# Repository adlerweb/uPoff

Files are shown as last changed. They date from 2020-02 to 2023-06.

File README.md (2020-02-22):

# µPoff - External deep sleep circuit
*µPoff* is a circuit placed high-side between your power source and your microcontroller. It is designed to cut power to the µC until a external sensor activates it. Additionally a onboard RTC can wake the µC in programmed intervals.

It is mainly aimed at battery powered sensor applications like door sensors, which also should report their battery level and presence regularly.

## Pinout

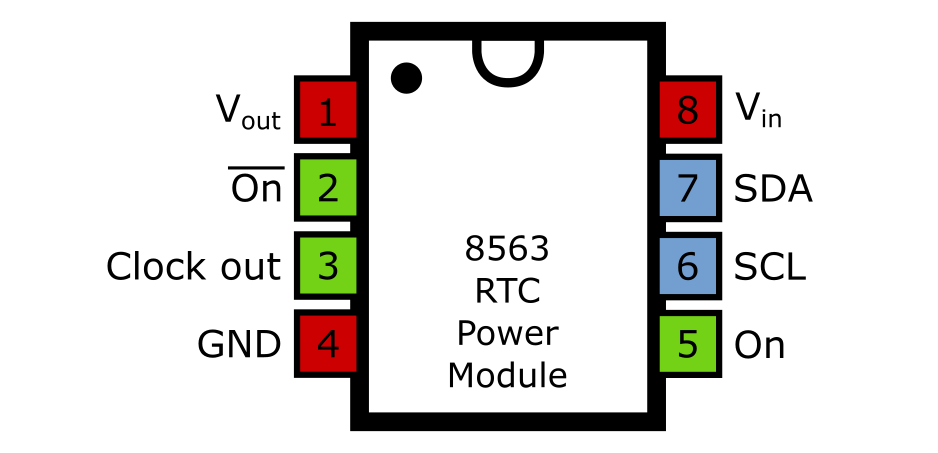
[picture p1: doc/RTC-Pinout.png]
Pinout diagram


## Connecting your µC

Remove the positive connection between your power source and µC. Connect the battery to **VCC** and your µC to **OUT**. Additionally connect **GND** to your existing ground. The external sensor should pull **^SW** low to activate the circuit. Lastly run a wire between one of your GPIO-Pins and **ON**. If you want to use the included RTC you'll also need to connect the I²C-Lines **SDA** and **SCL**. On AVR and STM32 based microcontrollers you'll have to use the predefined I²C pins, on ESP8266, ESP32 you can use any free GPIO.

## Software control

Usually power only stays on as long as **^ON** is low, however most tasks take longer to complete. To keep power on it is crucial to drive **ON** high as soon as your µC is started. When finished you can turn off power by driving **ON** LOW.

### Dependencies

 * Wire.h (usually included)
 * elpaso Rtc_Pcf8563 (https://github.com/elpaso/Rtc_Pcf8563)

### Manual wake only
```
#include "upoff.h"
UPOFF upoff;

void setup() {
  upoff.on(D1); //ON connected to D1
}

void loop() {
  //do something
  upoff.off();
}
```

### Manual and timed wake

```
#include "upoff.h"
UPOFF upoff;

bool reason;

void setup() {
  reason = upoff.on(D1, D2, D3); //D1 = ON; D2 = SDA; D3 = SCL
  //reason = upoff.on(D1, true); //Use predefined I²C-Pins

  /* Set clock */
  while(!upoff.isValid(false)) {
    upoff.setTime(20, 02, 02, 02, 02, 02); //2020-02-02 02:02:02
    yield();
  }
}

void loop() {
  pinMode(LED_BUILTIN, OUTPUT);
  if(reason) {
    /* either first boot or caused by RTC */
    byte loops=5;
    while(loops > 0) {
      digitalWrite(LED_BUILTIN, LOW);
      delay(100);
      digitalWrite(LED_BUILTIN, HIGH);
      delay(100);
      loops--;
    }
  }else{
    /* manual trigger */
    digitalWrite(LED_BUILTIN, LOW);
    delay(1000);
    digitalWrite(LED_BUILTIN, HIGH);
    delay(1000);
  }

  /* Sleep for 15 seconds */
  upoff.off(15);
}
```

## Power
While sleeping current draw for *µPoff* is ~10µA. Output should be fine for up to 1A.

## Common problems

### Boot-time vs. signal time
The external sensor has to keep **^ON** low until the µC is running and driving **ON**. Some µCs take several hundreds of milliseconds to boot. If your sensors pulse is too short you might be able to stretch it using some R+C magic.

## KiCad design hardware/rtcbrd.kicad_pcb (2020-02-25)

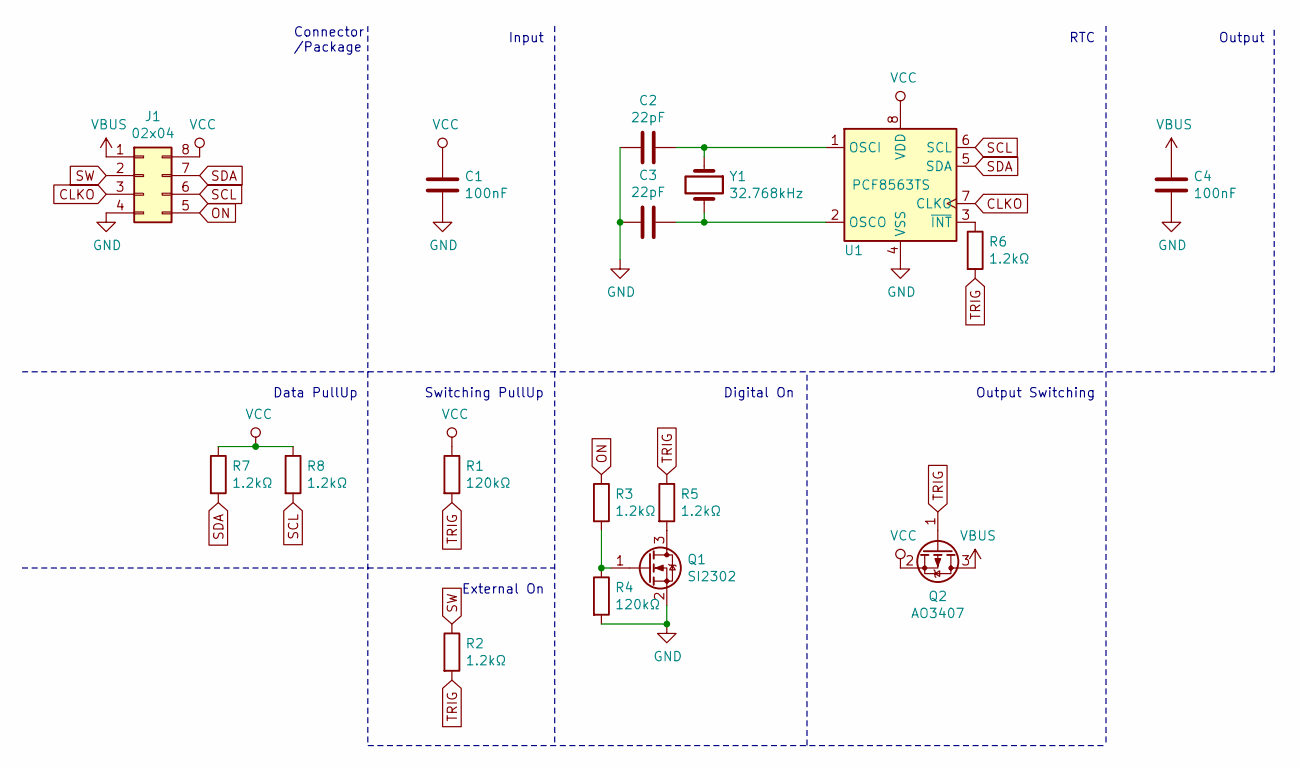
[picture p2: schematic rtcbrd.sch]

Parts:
C1, C4: 100nF; C_0402
C2, C3: 22pF; C_0402
J1: 02x04; DIP-8_W7.62mm
Q1: SI2302; SOT-23
Q2: AO3407; SOT-23
R1, R4: 120kΩ; R_0402
R2, R3, R5, R6, R7, R8: 1.2kΩ; R_0402
U1: PCF8563TS; HTSOP-8-1EP_3.9x4.9mm_Pitch1.27mm
Y1: 32.768kHz; Crystal_C38-LF_d3.0mm_l8.0mm_Horizontal

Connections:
CLKO: J1.3, U1.7 (CLKO)
GND: C1.1, C2.2, C3.2, C4.1, J1.4, Q1.2 (S), R4.2, U1.4 (VSS)
unnamed: C2.1, U1.1 (OSCI), Y1.1
unnamed: C3.1, U1.2 (OSCO), Y1.2
unnamed: Q1.1 (G), R3.2, R4.1
unnamed: Q1.3 (D), R5.2
unnamed: R6.1, U1.3 (~INT~)
ON: J1.5, R3.1
SCL: J1.6, R8.2, U1.6 (SCL)
SDA: J1.7, R7.2, U1.5 (SDA)
SW: J1.2, R2.1
TRIG: Q2.1 (G), R1.2, R2.2, R5.1, R6.2
VBUS: C4.2, J1.1, Q2.3 (D)
VCC: C1.2, J1.8, Q2.2 (S), R1.1, R7.1, R8.1, U1.8 (VDD)

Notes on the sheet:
Connector /Package
Input
RTC
Output
Output Switching
Digital On
Switching PullUp
External On
Data PullUp

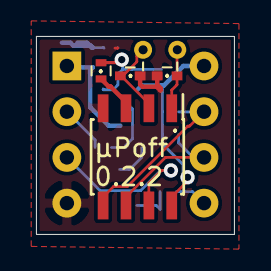
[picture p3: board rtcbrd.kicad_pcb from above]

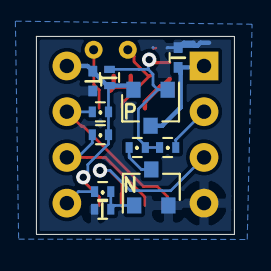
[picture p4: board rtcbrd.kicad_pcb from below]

Board: 2 copper layers, 11.0 x 11.0 mm, 17 parts (11 on the bottom side), 14 nets.

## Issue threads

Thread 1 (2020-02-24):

Missing i2c pullup resistors

FrederikWolter, 2020-02-24:

adlerweb, 2020-02-25:
https://github.com/adlerweb/uPoff/commit/7a002d55b8bd86f275d59c36e50ffc638167da36

Closed 2020-02-25.

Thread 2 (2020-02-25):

Component-List

JanLoebel, 2020-02-25:
Hi there,

I think for many people (specially beginner - like me) it would help to have a (example) component list and a wire-diagram without the pcb.

Example with Reichelt-Links (shop in Germany):

- U1: PCF8563TS -> https://www.reichelt.de/i-c-real-time-clock-tssop-8-pcf8563ts-5-p270122.html

- C2 / C3: 22pF Capacitor -> https://www.reichelt.de/glimmer-kondensator-22pf-100v-5-cy-22-2-22p-p42423.html

- C1 / C4: 100nF Capacitor -> https://www.reichelt.de/vielschicht-keramikkondensator-100n-10-x7r-2-5-100n-p22853.html

- R2 / R3 / R5 / R6: 1.2k Ohm Resistor -> https://www.reichelt.de/widerstand-metalloxyd-1-2-kohm-0207-1-0-w-5-1w-1-2k-p1768.html

- R1 / R4: 120k Ohm Resistor https://www.reichelt.de/widerstand-metalloxyd-120-kohm-0207-1-0-w-5-1w-120k-p1783.html

I'm missing the quartz crystal and the two mosfets, I was not able to find the right one so far. Of course you could also use other resistor/capacitor-types. Any other suggestions?

Best regards,
Jan

adlerweb, 2020-02-25:
When using KiCAD both are included. Also there is an interactive BOM located [inside the Hardware folder](https://raw.githubusercontent.com/adlerweb/uPoff/master/hardware/bom/ibom.html) - sadly GitHub doesn't render HTML directly, so you have to save and open it locally.

For your Links: I guess you're designing your own board or using a breadboard/prototype, otherwise you might want to check your footprints.

Crystal is [anything with 32.768kHz](https://www.reichelt.de/mini-uhrenquarz-0-032768-mhz-tc38-0-032768-p1089.html?), FETs are AO3407 (Q2/P) and SI2302 (Q1/N).

Items I used where mostly sourced from LCSC:

| Reference   | Quantity | Footprint | Value     | LCSC #  |
|-------------|----------|-----------|-----------|---------|
| C1,C4       | 2        | 0402      | 100nF     | C1525   |
| C2,C3       | 2        | 0402      | 22pF      | C115618 |
| R2,R3,R5,R6 | 4        | 0402      | 1.2kΩ     | C100581 |
| R1,R4       | 2        | 0402      | 120kΩ     | C384380 |
| U1          | 1        | HTSOP8    | PCF8563TS | C269877 |
| Y1          | 1        | C38       | 32.768kHz | C52082  |
| Q1          | 1        | SOT-23    | SI2302    | C351399 |
| Q2          | 1        | SOT-23    | AO3407    | C351408 |

JanLoebel, 2020-02-26:
Thanks :) I will have a look and KiCAD is new for me, so I will check how to see the wirediagramm. And yes I will start with a breadboard variant :) Thanks for the information!

Closed 2020-02-26.

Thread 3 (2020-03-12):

Missing ground connection at C2 & C3

FrederikWolter, 2020-03-12:
Hi,

I do not know if it is because I opened your board in EasyEDA, but I am shown that a ground connection of the two capacitors C2 & C3 is missing, since the ground plane is cut off by the quartz.

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

Isn't that necessary for the way it works?
Or should you make the connection in any case?

Thank you
Frederik

adlerweb, 2020-03-12:
Yes, GND is required. Seems to be a import bug in EasyEDA – ground is supposed to go between the RTC pins (and other places).
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
For me it looks like expansion is higher than intended (0.153mm or ~6mil). While you probably could add a trace there I would suggest to check expansion for both sides first, if you can fix it there there's probably a lower chance of errors in other parts of the board too.

FrederikWolter, 2020-03-12:
> looks like expansion is higher than intended (0.153mm or ~6mil)

It Works.
I almost thought that.
But I did not knew that EasyEDA overwrites these values when importing, nor to which value I should set it.

Thank you very much
Frederik

Closed 2020-03-12.

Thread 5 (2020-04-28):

RTC keeps VCCbus sometimes permanent high

FrederikWolter, 2020-04-28:
Hi,
I built the module (thanks for the idea). Everything works fine, except one thing.
Sometimes the RTC-Module gets stuck in the "ON-Position".
I use an Wemos D1 mini with the following code:

#include <Arduino.h>
#include "upoff.h"
UPOFF upoff;
bool reason;

void setup() {
  reason = upoff.on(2, 4, 5);          //ON = D4, SDA=D2 , SCL=D1
  Serial.begin(9600);
  while(!upoff.isValid(false)) {
    upoff.setTime(28, 04, 21, 02, 02, 02);  //YY.MM.DD HH:mm:ss
    yield();
    delay (100);
  }
}

void loop() {
   delay(2000);
   Serial.println("sleep ...");
   upoff.off(15);
}

Any idea how to solve this?

greet Frederik

FrederikWolter, 2020-05-04:
Hi,
I found that the delay(100) was the reason why it looked like the code was hanging.
After I removed it, it sometimes still takes several seconds to exit the while loop in setup, it seems.

any idea why?
Is it possible to leave the setTime out if there is no exact time needed just the off()-function?

Frederik

Closed 2020-07-10.

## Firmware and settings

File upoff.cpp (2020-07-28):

/**
  uPoff 

  @copyright 2020 Florian Knodt, www.adlerweb.info
*/

#ifndef UPOFF__CPP
    #define UPOFF__CPP
    //#define UPOFF_DEBUG

    #include "upoff.h"

    bool UPOFF::on(int onPin) {
        _uPoffOnPin = onPin;
        pinMode(_uPoffOnPin, OUTPUT);
        digitalWrite(_uPoffOnPin, HIGH);
        return false; //External reason
    }

    #ifndef UPOFF_NORTC

        bool UPOFF::rtcCheckReason() {
            bool status = false;
            rtc.getDateTime(); //Required to update status registers
            if(rtc.alarmActive() && rtc.alarmEnabled()) status = true;
            //if(rtc.timerActive() && rtc.timerEnabled()) status = true;
            if(rtc.timerActive()) status = true; //timerEnabled() was always 0 for me. Bug in library/silicon?
            
            rtc.clearAlarm();
            rtc.clearTimer();

            return status;
        }

        bool UPOFF::on(int onPin, bool i2c) {
            on(onPin);
            if(i2c) {
                Wire.begin();
            }

            return rtcCheckReason();
        }

        /* ESP8266 and ESP32 allow to specify custom pins for SDA/SCL */
        #if defined(ESP8266) or defined(ESP32)
            /**
             * Keep power on
             * @param int Pin used to keep power on ("ON")
             * @param int Pin used for I²C SDA
             * @param int Pin used for I²C SCL
             * @return true if initialized
             */
            bool UPOFF::on(int onPin, int sda, int scl) {
                on(onPin);
                Wire.begin(sda, scl);
                
                return rtcCheckReason();
            }
        #endif

        bool UPOFF::isValid(bool checkVolt) {
             if(checkVolt && !rtc.getVoltLow()) {
                #ifdef UPOFF_DEBUG
                    Serial.println("E:Voltage");
                #endif
                return false;
             }
             byte temp;
             temp = rtc.getMonth();
             if(temp > 12 || temp == 0 ) {
                #ifdef UPOFF_DEBUG
                    Serial.println("E:Month");
                #endif
                return false;
             }
             temp = rtc.getDay();
             if(temp > 31 || temp == 0 ) {
                #ifdef UPOFF_DEBUG
                    Serial.println("E:Day");
                #endif
                return false;
             }
             temp = rtc.getHour();
             if(temp > 24 ) {
                #ifdef UPOFF_DEBUG
                    Serial.println("E:Hour");
                #endif
                return false;
             }
             temp = rtc.getMinute();
             if(temp > 59 ) {
                #ifdef UPOFF_DEBUG
                    Serial.println("E:Minute");
                #endif
                return false;
             }
             temp = rtc.getSecond();
             if(temp > 59 ) {
                #ifdef UPOFF_DEBUG
                    Serial.println("E:Second");
                #endif
                return false;
             }
             return true;
        }

        void UPOFF::setTime(uint8_t year, uint8_t month, uint8_t day, uint8_t hour, uint8_t minute, uint8_t second) {
            byte weekday = rtc.whatWeekday(day, month, 0, year);
            rtc.initClock();
            delay(10);
            rtc.setDateTime(day, weekday, month, 0, year, hour, minute, second);
            delay(10);
            rtc.clearVoltLow();
        }

        String UPOFF::getTime(void) {
            String out;
            out += rtc.formatDate(RTCC_DATE_ASIA); //Actually ISO 8601 international format. Use it.
            out += " ";
            out += rtc.formatTime(RTCC_TIME_HMS);
            return out;
        }

        void UPOFF::off(unsigned long seconds) {
            if(seconds < 240) {
                //When below 4 minutes we're using a second-countdown
                #ifdef UPOFF_DEBUG
                    Serial.print("Setting timer to ");
                    Serial.print(seconds);
                    Serial.println(" Seconds @ 1Hz");
                #endif
                rtc.setTimer(seconds, TMR_1Hz, false);
            }else{
                byte dev = seconds % 60;
                seconds /= 60;
                if(dev >= 30)
                    seconds++;

                #ifdef UPOFF_DEBUG
                    Serial.print("Not enough bits - calculated ");
                    Serial.print(seconds);
                    Serial.println(" Minutes");
                #endif

                if(seconds < 240) {
                    //Between 4 minutes and 4 hours we're using a minute based countdown
                    //Triggers might deviate up to 30 seconds from target

                    #ifdef UPOFF_DEBUG
                        Serial.print("Setting timer to ");
                        Serial.print(seconds);
                        Serial.println(" Minutes @ 1/60Hz");
                    #endif

                    rtc.setTimer(seconds, TMR_1MIN, false);
                }else{
                    //Above 4 hours we use the alarm functionality. With luck it works
                    //even tho the calculations are…uhm…interesting

                    #ifdef UPOFF_DEBUG
                        Serial.println("Switching to alarm mode. Current Time:");
                        Serial.println(getTime());
                    #endif

                    uint32_t target = 0;
                    target += rtc.getDay() * 24 * 60;
                    target += rtc.getHour() * 60;
                    target += rtc.getMinute();

                    #ifdef UPOFF_DEBUG
                        Serial.println("Second calculation:");
                        Serial.print(target);
                    #endif

                    target += seconds;

                    #ifdef UPOFF_DEBUG
                        Serial.print(" + ");
                        Serial.print(seconds);
                        Serial.print(" = ");
                        Serial.println(target);
                    #endif

                    byte aDay = (target / (24*60));
                    target -= (aDay * (24*60));
                    byte aHour = (target / 60);
                    target -= (aHour * 60);
                    byte aMinute = target;

                    #ifdef UPOFF_DEBUG
                        Serial.print("D:");
                        Serial.print(aDay);
                        Serial.print(" H:");
                        Serial.print(aHour);
                        Serial.print(" M:");
                        Serial.println(aMinute);
                    #endif

                    byte daysThisMonth = rtc.daysInMonth(rtc.getCentury(), rtc.getYear(), rtc.getMonth());
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

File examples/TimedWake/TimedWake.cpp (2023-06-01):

#include <Arduino.h>
#include "upoff.h"

UPOFF upoff;
bool reason;

void setup() {
  /**
   * Keep circuit switched on and read reason for wake
   * D1 = On-Pin
   * D3 = SDA
   * D2 = SCL
   */
  reason = upoff.on(D1, D3, D2);

  /**
   * RTC may do silly stuff if no date is set
   * if it appears to be unprogrammed choose a
   * random date, as we only use relative times
   * anyway. Feel free to sync with NTP if desired.
   */
  while(!upoff.isValid(false)) {
    upoff.setTime(20, 02, 02, 02, 02, 02);
    yield();
  }
}

void loop() {
  pinMode(LED_BUILTIN, OUTPUT);
  if(reason) {
    /* either first boot or caused by RTC */
    byte loops=5;
    while(loops > 0) {
      digitalWrite(LED_BUILTIN, LOW);
      delay(100);
      digitalWrite(LED_BUILTIN, HIGH);
      delay(100);
      loops--;
    }
  }else{
    /* manual trigger */
    digitalWrite(LED_BUILTIN, LOW);
    delay(1000);
    digitalWrite(LED_BUILTIN, HIGH);
    delay(1000);
  }

  /* Sleep for 15 seconds */
  upoff.off(15);
}

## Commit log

2020-02-09 Add I²C-Info for AVR/STM32 vs ESP*
2020-02-23 Do not ignore BOM
2020-02-25 Add I²C Pull-Up; Move value markings
    [rtcbrd.kicad_pcb, rtcbrd.sch]
2020-07-28 Fix incorrect validity check
    Rumors say midnight is in fact a valid time. Too much copy&paste. Fixes #6.
    [upoff.cpp]
